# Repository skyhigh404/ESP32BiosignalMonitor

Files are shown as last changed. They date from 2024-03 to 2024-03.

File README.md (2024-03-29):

# ESP32 Biosignal Monitor

This project is a physiological signal acquisition system developed using ESP32-­WROOM-­32E, ADS1293, and AD5941. It is designed to collect various physiological signals, such as electrocardiograms (ECG) and electrodermal activity (EDA), and transmit them wirelessly using websockets. It also can calculate the heart rate by extracting the R peaks from the ECG signal. It employed notch filters and wavelet filters for ECG signal denoising. 

## Introduction
### ECG Signal Denoising
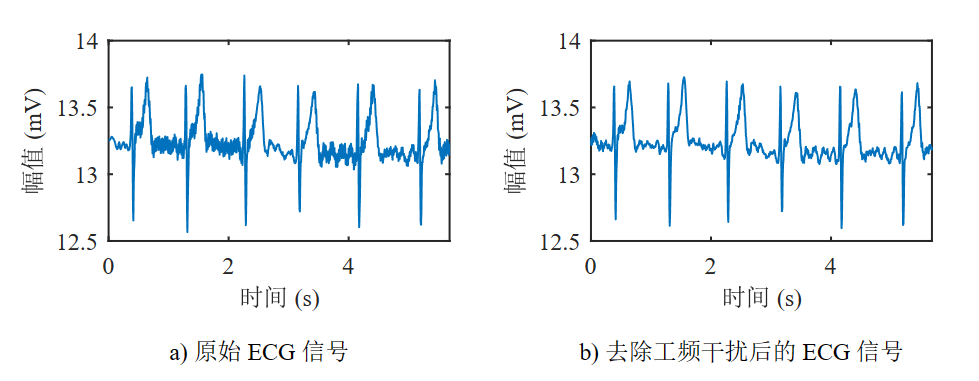
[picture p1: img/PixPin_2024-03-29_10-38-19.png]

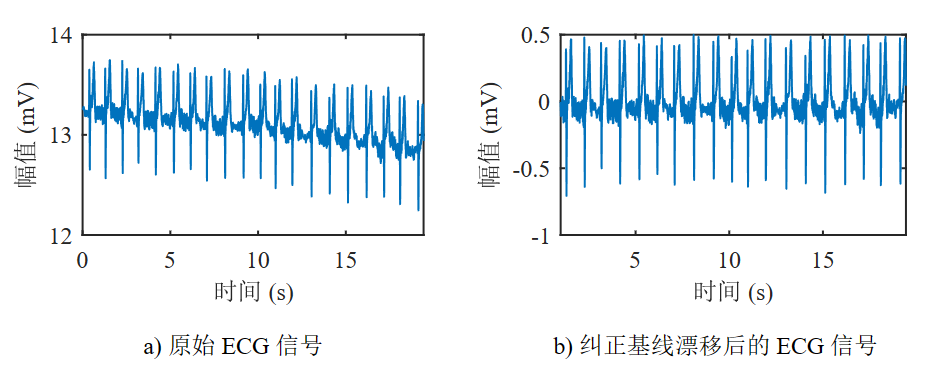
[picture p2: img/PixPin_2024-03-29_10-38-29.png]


### Heart Rate Extraction
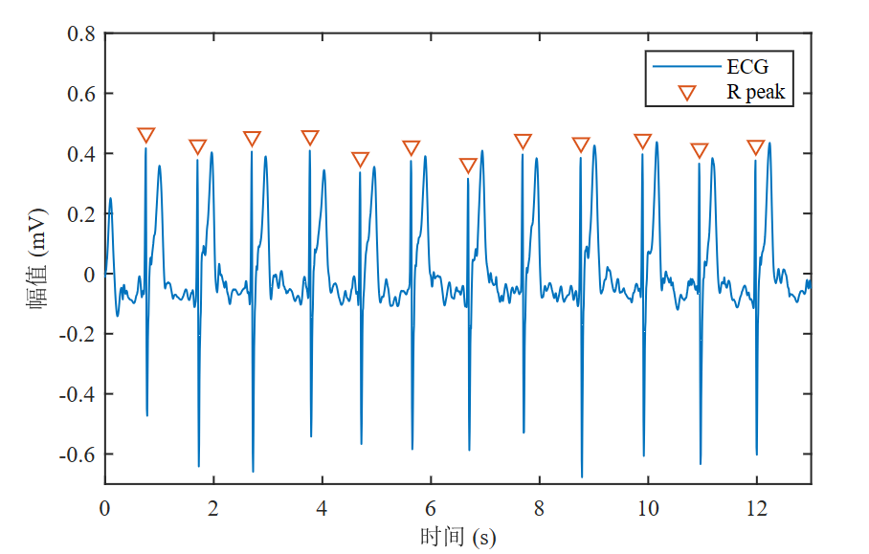
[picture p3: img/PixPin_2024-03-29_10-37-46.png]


### Schematic Diagram
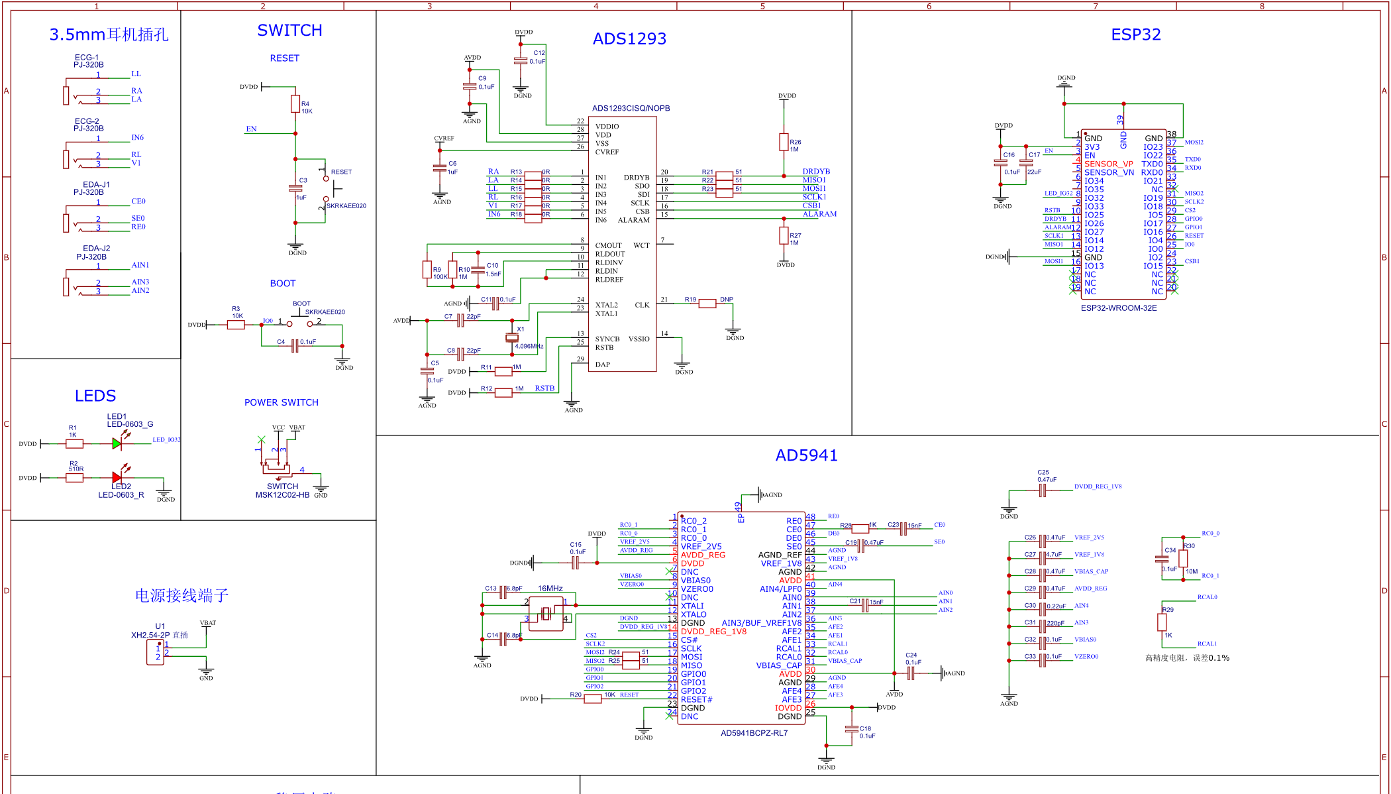
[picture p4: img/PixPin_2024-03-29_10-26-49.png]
Schematic Diagram


### Circuit Diagram
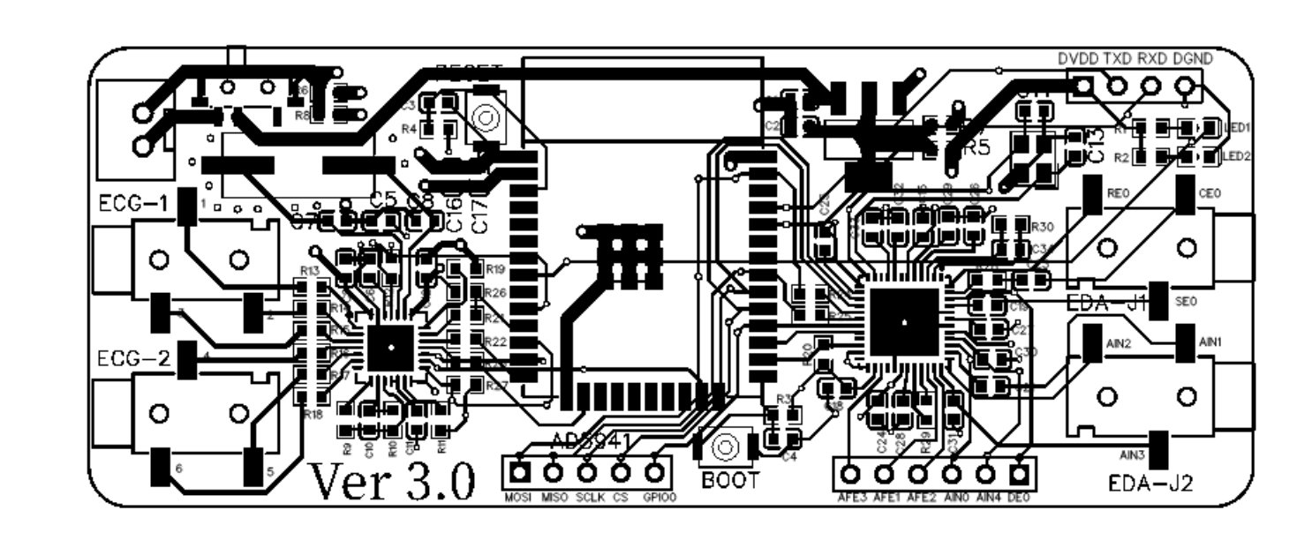
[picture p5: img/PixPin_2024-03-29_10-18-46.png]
Circuit Diagram


### Shell Design
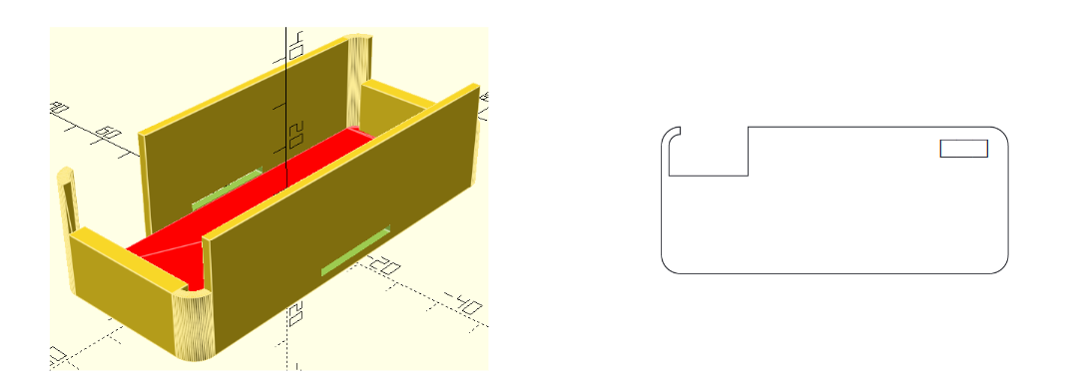
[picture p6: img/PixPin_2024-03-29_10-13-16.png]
Shell design


### Physical Prototype
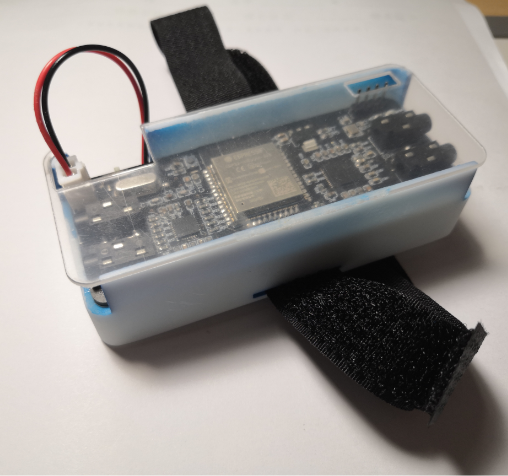
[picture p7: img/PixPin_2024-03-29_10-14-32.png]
Physical Prototype


## Usage

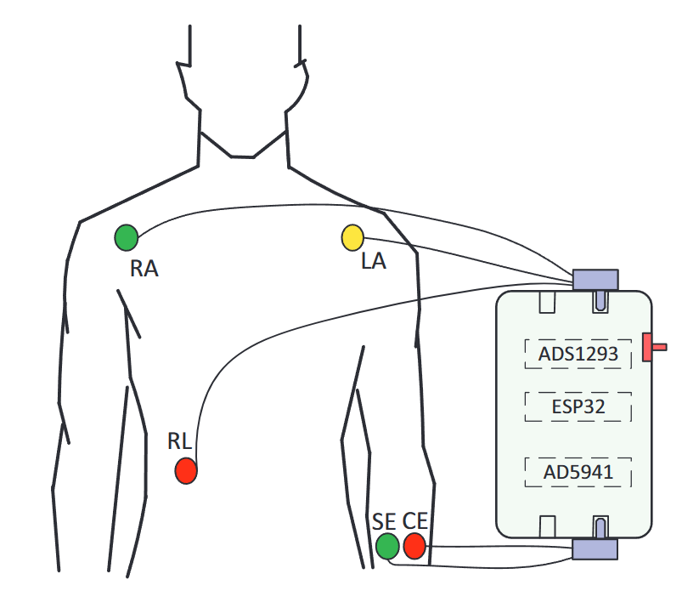
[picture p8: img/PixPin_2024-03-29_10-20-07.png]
Connection Method


## Acknowledgements
This project makes use of the following open-source libraries:

+ [esp32-websocket](https://github.com/Molorius/esp32-websocket) - A WebSocket library for the ESP32, enabling efficient real-time communication for IoT devices. This library forms the backbone of our system's wireless data transmission capabilities.
+ [wavelib](https://github.com/rafat/wavelib) - A Wavelet Transform library that provides various signal processing functions that help denoise the physiological signals collected by our system.

Special thanks to the authors and contributors of these projects for their valuable work, which significantly enhanced the functionality and performance of our physiological signal acquisition system.

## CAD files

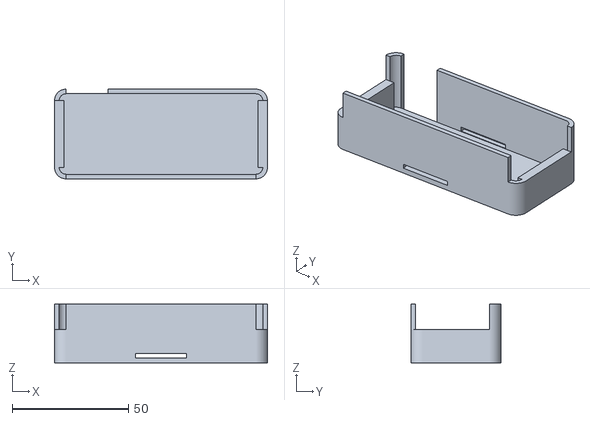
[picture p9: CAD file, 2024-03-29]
hardware/外壳/外壳.stl
91.8 x 38.7 x 25.4

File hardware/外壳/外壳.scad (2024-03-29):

$fa = 1;
$fs = 0.4;

// 考虑了0.2mm公差，x和y方向尺寸
width = 87.8;
height = 34.7; 
// 倒角直径
diameter = 6;

//底座打印厚度
thickness = 2;

//边缘厚度
edge_thick = 2;

//绑带厚度
tape_thick = 1.8;

//绑带宽度
tape_width = 22;

//电池厚度10mm，绑带厚度
battery_thick = 10.6+tape_thick;



//顶部高度
top_high = 11;

color("red")
linear_extrude(height = thickness){
    //做倒角
    minkowski(){
        square([width-diameter,height-diameter],center = true);
    circle(d = diameter);
}
}



// 四分之一圆环
module quater_ring(large_diameter, small_diameter){
intersection(){
difference(){
circle(d=large_diameter);
circle(d=small_diameter);
}
square(large_diameter);    
}
}

// 外边界
// 右上角
translate([width/2-diameter/2-0.001,height/2-diameter/2-0.001,0])
linear_extrude(height = battery_thick+thickness+top_high){
quater_ring(diameter+2*edge_thick,diameter);
}

// 左上角
translate([-width/2+diameter/2+0.001,height/2-diameter/2-0.001,0])
linear_extrude(height = battery_thick+thickness+top_high){
rotate([0,0,90])
quater_ring(diameter+2*edge_thick,diameter);
}

// 左下角
translate([-width/2+diameter/2+0.001,-height/2+diameter/2+0.001,0])
linear_extrude(height = battery_thick+thickness){
rotate([0,0,180])
quater_ring(diameter+2*edge_thick,diameter);
}


// 右下角
translate([width/2-diameter/2-0.001,-height/2+diameter/2+0.001,0])
linear_extrude(height = battery_thick+thickness){
rotate([0,0,270])
quater_ring(diameter+2*edge_thick,diameter);
}

// 左挡板，并托住电路板
translate([-width/2-edge_thick+0.001,-height/2+diameter/2,0])
cube([edge_thick+2,height-diameter,battery_thick+thickness]);

// 右挡板，并托住电路板
translate([width/2-2-0.001,-height/2+diameter/2,0])
cube([edge_thick+2,height-diameter,battery_thick+thickness]);

// 前挡板，绑带孔
difference(){
translate([-(width-diameter)/2,-height/2-edge_thick+0.001,0])
cube([width-diameter,edge_thick,battery_thick+thickness+top_high]);
translate([0,0,tape_thick/2+thickness+0.2])
cube([tape_width,50,tape_thick],center = true);
}
// 后挡板，留出电池线通道，绑带孔
difference(){
translate([-(width-diameter)/2+18,height/2-0.001,0])
cube([width-diameter-18,edge_thick,battery_thick+thickness+top_high]);
translate([0,0,tape_thick/2+thickness+0.2])
cube([tape_width,50,tape_thick],center = true);
}

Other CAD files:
hardware/外壳/顶盖.dwg

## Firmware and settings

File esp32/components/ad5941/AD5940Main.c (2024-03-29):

/*!
 *****************************************************************************
 @file:    AD5940Main.c
 @author:  Neo Xu (have been modified)
 @brief:   Used to control specific application and furfur process data.
 -----------------------------------------------------------------------------

Copyright (c) 2017-2019 Analog Devices, Inc. All Rights Reserved.

This software is proprietary to Analog Devices, Inc. and its licensors.
By using this software you agree to the terms of the associated
Analog Devices Software License Agreement.

*****************************************************************************/
/**
 * @addtogroup AD5940_System_Examples
 * @{
 *  @defgroup BioElec_Example
 *  @{
 */
#include "ad5940.h"
#include "AD5940.h"
#include <stdio.h>
#include "string.h"
#include "math.h"
#include "ElectrodermalActivity.h"
#include "freertos/FreeRTOS.h"
#include "freertos/task.h"
#include "freertos/queue.h"
#include "freertos/semphr.h"
#include "ad5941.h"
#include "esp_log.h"

#define APPBUFF_SIZE 512
uint32_t AppBuff[APPBUFF_SIZE];
float LFOSCFreq; /* Measured LFOSC frequency */
uint32_t ResistorForBaseline = 0;
static const char *TAG = "ad5941";

/* print EDA result to uart */
AD5940Err EDAShowResult(void *pData, uint32_t DataCount, QueueHandle_t ad5941_queue)
{
  float RtiaMag;
  /*Process data*/
  fImpCar_Type *pImp = (fImpCar_Type *)pData;
  AppEDACtrl(EDACTRL_GETRTIAMAG, &RtiaMag);

  /*Process data*/
  for (int i = 0; i < DataCount; i++)
  {
    float mag, phase;
    fImpCar_Type res;
    res = pImp[i];
    res.Real += ResistorForBaseline; /* Show the real result of impedance under test(between F+/S+) */
    mag = AD5940_ComplexMag(&res);
    phase = AD5940_ComplexPhase(&res) * 180 / MATH_PI;

    xQueueSendToBack(ad5941_queue, &mag, portMAX_DELAY);
    // ESP_LOGI(TAG, "Rtia:%.2f,(Real,Image):(%.2f,%.2f)Ohm---Mag:%.2fOhm,Phase:%.2f`",
    //          RtiaMag, res.Real, res.Image, mag, phase);
  }
  return 0;
}

/* Initialize AD5940 basic blocks like clock */
static int32_t AD5940PlatformCfg(void)
{
  CLKCfg_Type clk_cfg;
  FIFOCfg_Type fifo_cfg;
  SEQCfg_Type seq_cfg;
  AGPIOCfg_Type gpio_cfg;
  LFOSCMeasure_Type LfoscMeasure;

  /* Use hardware reset */
  AD5940_HWReset();
  /* Platform configuration */
  AD5940_Initialize();

  /* Step1. Configure clock */
  clk_cfg.ADCClkDiv = ADCCLKDIV_1;
  clk_cfg.ADCCLkSrc = ADCCLKSRC_HFOSC;
  clk_cfg.SysClkDiv = SYSCLKDIV_1;
  clk_cfg.SysClkSrc = SYSCLKSRC_HFOSC;
  clk_cfg.HfOSC32MHzMode = bFALSE;
  clk_cfg.HFOSCEn = bTRUE;
  clk_cfg.HFXTALEn = bFALSE;
  clk_cfg.LFOSCEn = bTRUE;
  AD5940_CLKCfg(&clk_cfg);
  /* Step2. Configure FIFO and Sequencer*/
  fifo_cfg.FIFOEn = bFALSE;
  fifo_cfg.FIFOMode = FIFOMODE_FIFO;
  fifo_cfg.FIFOSize = FIFOSIZE_4KB; /* 4kB for FIFO, The reset 2kB for sequencer */
  fifo_cfg.FIFOSrc = FIFOSRC_DFT;
  fifo_cfg.FIFOThresh = 4;   // AppBIACfg.FifoThresh;        /* DFT result. One pair for RCAL, another for Rz. One DFT result have real part and imaginary part */
  AD5940_FIFOCfg(&fifo_cfg); /* Disable to reset FIFO. */
  fifo_cfg.FIFOEn = bTRUE;
  AD5940_FIFOCfg(&fifo_cfg); /* Enable FIFO here */
  /* Configure sequencer and stop it */
  seq_cfg.SeqMemSize = SEQMEMSIZE_2KB;
  seq_cfg.SeqBreakEn = bFALSE;
  seq_cfg.SeqIgnoreEn = bFALSE;
  seq_cfg.SeqCntCRCClr = bTRUE;
  seq_cfg.SeqEnable = bFALSE;
  seq_cfg.SeqWrTimer = 0;
  AD5940_SEQCfg(&seq_cfg);

  /* Step3. Interrupt controller */
  AD5940_INTCCfg(AFEINTC_1, AFEINTSRC_ALLINT, bTRUE);         /* Enable all interrupt in Interrupt Controller 1, so we can check INTC flags */
  AD5940_INTCCfg(AFEINTC_0, AFEINTSRC_DATAFIFOTHRESH, bTRUE); /* Interrupt Controller 0 will control GP0 to generate interrupt to MCU */
  AD5940_INTCClrFlag(AFEINTSRC_ALLINT);
  /* Step4: Reconfigure GPIO */
  gpio_cfg.FuncSet = GP6_SYNC | GP5_SYNC | GP4_SYNC | GP2_EXTCLK | GP1_SYNC | GP0_INT;
  gpio_cfg.InputEnSet = AGPIO_Pin2;
  gpio_cfg.OutputEnSet = AGPIO_Pin0 | AGPIO_Pin1 | AGPIO_Pin4 | AGPIO_Pin5 | AGPIO_Pin6;
  gpio_cfg.OutVal = 0;
  gpio_cfg.PullEnSet = 0;
  AD5940_AGPIOCfg(&gpio_cfg);

  AD5940_SleepKeyCtrlS(SLPKEY_UNLOCK); /* Enable AFE to enter sleep mode. */

  /* Measure LFOSC frequency */
  LfoscMeasure.CalDuration = 1000.0; /* 1000ms used for calibration. */
  LfoscMeasure.CalSeqAddr = 0;
  LfoscMeasure.SystemClkFreq = 16000000.0f; /* 16MHz in this firmware. */
  AD5940_LFOSCMeasure(&LfoscMeasure, &LFOSCFreq);
  printf("Freq:%f\n", LFOSCFreq);

  return 0;
}

void AD5940EDAStructInit(void)
{
  AppEDACfg_Type *pCfg;

  AppEDAGetCfg(&pCfg);
  pCfg->MaxSeqLen = 512;

  pCfg->LfoscClkFreq = 32000;        /* Don't do LFOSC calibration now. We assume the default LFOSC is trimmed. */
  pCfg->RtiaAutoScaleEnable = bTRUE; /* We manually select resistor value. */
  pCfg->LptiaRtiaSel = LPTIARTIA_120K;
  pCfg->SinAmplitude = 1100 * 3 / 4; /* Set excitation voltage to 0.75 times of full range. */
  pCfg->SinFreq = 100.0f;
  pCfg->SampleFreq = 400.0f; /* Do not change sample frequency unless you know how it works. */
  pCfg->EDAODR = 4.0f;       /* ODR decides how frequently to start the engine to measure impedance. */
  pCfg->FifoThresh = 4;      /* The minimum threshold value is 4, and should always be 4*N, where N is 1,2,3... */
  pCfg->bParaChanged = bTRUE;
}

void AD5940_Main(void *pvParametersd)
{
  ad5941_info_t ad5941_info = *(ad5941_info_t *)pvParametersd;

  uint32_t temp;
  fImpCar_Type EDABase =
      {
          .Real = 24299.84f,
          .Image = -110778.71f,
      };

  AD5940PlatformCfg();

  AD5940EDAStructInit(); /* Configure your parameters in this function */

  AppEDAInit(AppBuff, APPBUFF_SIZE); /* Initialize BIA application. Provide a buffer, which is used to store sequencer commands */
  AppEDACtrl(APPCTRL_START, 0);      /* Control BIA measurement to start. Second parameter has no meaning with this command. */
  AppEDACtrl(EDACTRL_SETBASE, &EDABase);
  ResistorForBaseline = 20000; /* Above result is obtained using 20kOhm resistor on BioElec Rev C board. */
  ESP_LOGI(TAG, "AD5941 initialization complete, free heap size %u.", esp_get_free_heap_size());

  while (1)
  {
    xSemaphoreTake(ad5941_info.gpio0_semaphore_handle, portMAX_DELAY);
    // TickType_t start_time = xTaskGetTickCount();
    temp = APPBUFF_SIZE;
    AppEDAISR(AppBuff, &temp);                              /* Deal with it and provide a buffer to store data we got */
    EDAShowResult(AppBuff, temp, ad5941_info.ad5941_queue); /* Show the results to UART */
    // TickType_t end_time = xTaskGetTickCount();
    // ESP_LOGI(TAG, "excute time: %u remain stack size: %u.",end_time-start_time, uxTaskGetStackHighWaterMark(NULL));
  }
}

uint32_t rst_eda_base(uint32_t para1, uint32_t para2)
{
  printf("Reset EDA impedance baseline\n");
  ResistorForBaseline = 0;
  AppEDACtrl(EDACTRL_RSTBASE, 0);
  return 0;
}

uint32_t set_eda_base(uint32_t para1, uint32_t para2)
{
  fImpCar_Type ImpAVR;
  printf("Set EDA impedance baseline with current measured impedance average result\n");
  printf("Resistor used to measure baseline is %dOhm\n", para1);
  ResistorForBaseline = para1;
  AppEDACtrl(EDACTRL_GETAVR, &ImpAVR);
  AppEDACtrl(EDACTRL_SETBASE, &ImpAVR);
  return 0;
}

uint32_t get_average_imp(uint32_t para1, uint32_t para2)
{
  fImpCar_Type ImpAVR;
  printf("Measured average impedance result is:\n");
  AppEDACtrl(EDACTRL_GETAVR, &ImpAVR);
  printf("(Real,Image)=(%.2f,%.2f)Ohm\n", ImpAVR.Real, ImpAVR.Image);
  return 0;
}

uint32_t eda_start(uint32_t para1, uint32_t para2)
{
  printf("Start EDA measurement\n");
  AppEDACtrl(APPCTRL_START, 0);
  return 0;
}

uint32_t eda_stop(uint32_t para1, uint32_t para2)
{
  printf("Stop EDA measurement right now!!\n");
  AppEDACtrl(APPCTRL_STOPNOW, 0);
  return 0;
}

/**
 * @}
 * @}
 * */

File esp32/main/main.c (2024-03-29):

#include <stdio.h>
#include <malloc.h>
#include <string.h>
#include <time.h>
#include "freertos/FreeRTOS.h"
#include "freertos/task.h"
#include "freertos/queue.h"
#include "esp_log.h"
#include "esp_system.h"
#include "driver/gpio.h"
#include "unistd.h"
#include "ads1293.h"
#include "ad5941.h"
#include "wifi.h"
#include "websocketClient.h"
#include "filter.h"
#include "led.h"

struct
{
    ADS1293_cfg_t ads1293_config;
    AD5941_cfg_t ad5941_config;
    filter_cfg_t filter_config;
    wifi_cfg_t wifi_config;
} system_config;

void app_main(void)
{
    printf("Hey you! Idf ver: " IDF_VER " free heap size %u.\n", esp_get_free_heap_size());

    memset(&system_config, 0, sizeof(system_config));

    // Setting ads1293_config and filter_config parameters
    system_config.ads1293_config.leads = 1;
    system_config.ads1293_config.ads1293_queue_size = 200;
    system_config.ads1293_config.ADCmax = 0xC35000;

    system_config.filter_config.filter_queue_size = 200;
    strcpy(system_config.filter_config.wname, "db6");
    system_config.filter_config.level = 7;
    system_config.filter_config.sig_length = 50;
    system_config.filter_config.heart_rate_queue = xQueueCreate(1, sizeof(int));

    if (system_config.ads1293_config.leads == 5)
    {
        system_config.ads1293_config.ads1293_queue =
            xQueueCreate(system_config.ads1293_config.ads1293_queue_size, sizeof(ecg_5leads_data_t));
        system_config.filter_config.filter_queue =
            xQueueCreate(system_config.filter_config.filter_queue_size, sizeof(double) * 3);
    }
    else if (system_config.ads1293_config.leads == 3)
    {
        system_config.ads1293_config.ads1293_queue =
            xQueueCreate(system_config.ads1293_config.ads1293_queue_size, sizeof(ecg_3leads_data_t));
        system_config.filter_config.filter_queue =
            xQueueCreate(system_config.filter_config.filter_queue_size, sizeof(double) * 2);
    }
    else if (system_config.ads1293_config.leads == 1)
    {
        system_config.ads1293_config.ads1293_queue =
            xQueueCreate(system_config.ads1293_config.ads1293_queue_size, sizeof(ecg_1leads_data_t));
        system_config.filter_config.filter_queue =
            xQueueCreate(system_config.filter_config.filter_queue_size, sizeof(double) * 1);
    }

    // Setting ad5941_config parameters
    system_config.ad5941_config.ad5941_queue_size = 20;
    system_config.ad5941_config.ad5941_queue =
        xQueueCreate(system_config.ad5941_config.ad5941_queue_size, sizeof(float));

    // Setting wifi_config parameters
    strcpy(system_config.wifi_config.ssid, "TP-LINK_083E");
    strcpy(system_config.wifi_config.password, "11031103");
    system_config.wifi_config.max_retry = 50;

    // Create queue set
    QueueSetHandle_t send_data_queue_set = xQueueCreateSet(system_config.filter_config.filter_queue_size + system_config.ad5941_config.ad5941_queue_size + 1);
    xQueueAddToSet(system_config.filter_config.filter_queue, send_data_queue_set);
    xQueueAddToSet(system_config.ad5941_config.ad5941_queue, send_data_queue_set);
    xQueueAddToSet(system_config.filter_config.heart_rate_queue, send_data_queue_set);

    // Check everything was created.
    configASSERT(send_data_queue_set);
    configASSERT(system_config.filter_config.filter_queue);
    configASSERT(system_config.ad5941_config.ad5941_queue);
    configASSERT(system_config.filter_config.heart_rate_queue);

    ESP_ERROR_CHECK(gpio_install_isr_service(ESP_INTR_FLAG_LEVEL3));

    // Initialize each module
    ad5941_init(system_config.ad5941_config);
    ledc_init();
    ledc_set_blink_mode(ALWAYS_BRIGHT);
    ESP_LOGI("ads1293", "free heap size %u", esp_get_free_heap_size());
    wifi_init(system_config.wifi_config);
    ESP_LOGI("wifi", "free heap size %u", esp_get_free_heap_size());
    web_server_init(system_config.filter_config.filter_queue,
                    system_config.ad5941_config.ad5941_queue,
                    system_config.filter_config.heart_rate_queue,
                    send_data_queue_set,
                    system_config.ads1293_config.leads);
    ESP_LOGI("webserver", "free heap size %u", esp_get_free_heap_size());

    ads1293_init(system_config.ads1293_config); // Changing the initialization order will cause an error
    filter_init(&system_config.filter_config, system_config.ads1293_config);
}
